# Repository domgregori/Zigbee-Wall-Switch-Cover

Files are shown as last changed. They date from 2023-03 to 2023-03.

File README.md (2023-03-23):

# Zigbee Wall Switch Cover
This is a zigbee button that can go over a standard US wall switch. This can be handy to control smartbulbs (or whatever else) in a place where you are unable to install smart switches, allowing the switch to remain in the on position and activating the bulb with the front buttons.

This is built using [FreePad](https://github.com/diyruz/freepad) firmware for the E18-MS1-PCB zigbee module. For the zigbee coordinator I use [zigbee2mqtt](https://www.zigbee2mqtt.io/)

# Photos

PCB_Front PCB_Back

PCB_On_Wall Case_On_Wall zigbee_switch

# Programming
This is the wiring diagram between the PCB and CC Debugger

WiringDiagram

To program the module, use [TI SmartRF Flash Programmer](https://www.ti.com/tool/FLASH-PROGRAMMER) **NOT v2** and a CC Debugger

Use the DIYRuZ_FreePad_PM3.hex file from [FreePad](https://github.com/diyruz/freepad/releases) releases for longer battery life.
  
# Ordering
You can use the gerber files in the [PCB folder](PCB/) to order from a PCB manufacturer (I used jlcpcb)

### Part list
Parts can be found in [BOM Folder](BOM/bom.csv)
- 2x 2032 Battery Holder
- 3mm LED
- 5-pin 2.54 (standard) header for programming (if using the 3D printed case that I provided, these headers needed to be removed after programming)
- 2x 1k resistors, 0805
- 10k resistor, 0805
- 2x push buttons, 6x6x4.5mm
- E18-MS1-PCB

# Case
The 3D printed case file can be found in the [Case folder](Case/)

Printed with 20% Infill, Front face on bed with supports for the mounting holes

The PCB has 2mm mounting holes, but I did not use them in this case

Case (Custom)

# Notes
- Orient the **"TOP"** part of the PCB towards the direction of the switch (so upside down if your switch in on in the down position)
- Button 1 (SW1) is the pairing button
- Pair using the info at [Freepad: How to join](https://github.com/diyruz/freepad#how-to-join)
- I highly reccomend setting at least one of the buttons to MOMENTARY mode for quicker respose using the [Freedpad: Working modes](https://github.com/diyruz/freepad#work-modes) guide
- Only one battery is required to run but I use 2 so I get a longer run time
- If using zigbee2mqtt, don't use the outdated CC2531 board. It killed my batteries in days and pairing problems. I recomend the Sonoff ZBDongle-P (**Not model ZBDongle-E**)

### How I use mine
- Top button is set to MOMENTARY mode and toggles light on/off
- Bottom button press toggles between scenes from Home Assistant
- Bottom button hold goes into a dimming mode that allows me to brighten with the top button and dim with the bottom button
- Bottom double press sets light to a night light

- I achieve these by using a mix of Home Assistant automations as well as Node Red

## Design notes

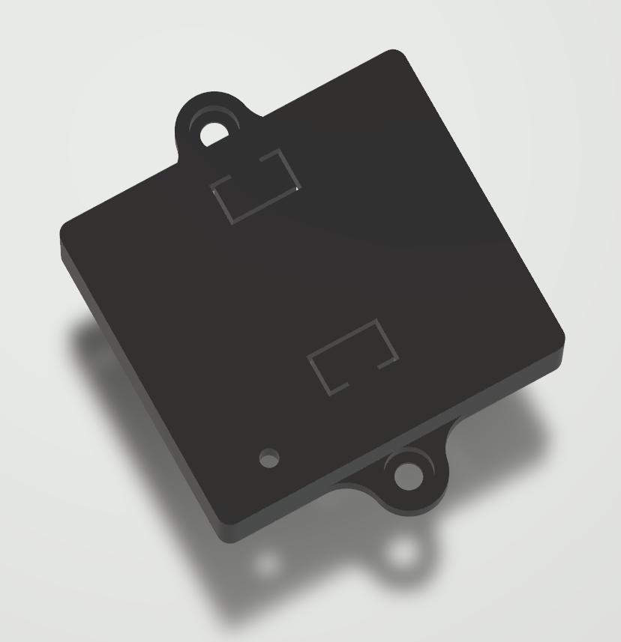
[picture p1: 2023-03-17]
Case/Case.png

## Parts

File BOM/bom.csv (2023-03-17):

Designator | Footprint | Quantity | Value | LCSC Part #
BT1, BT2 | BatteryHolder_Keystone_3002_1x2032 | 2 | Battery_Cell
D1 | LED_D3.0mm | 1 | LED
H1, H2, H3 | MountingHole_2mm | 3 | MountingHole
J1 | PinHeader_1x05_P2.54mm_Vertical | 1 | Debug
R1 | 0805 | 1 | 1k
R2 | 0805 | 1 | 1k
R3 | 0805 | 1 | 10k
SW1, SW2 | SW_PUSH_6mm_H4.3mm | 2 | SW_Push
U1 | E18-MS1-PCB | 1 | E18-MS1-PCB

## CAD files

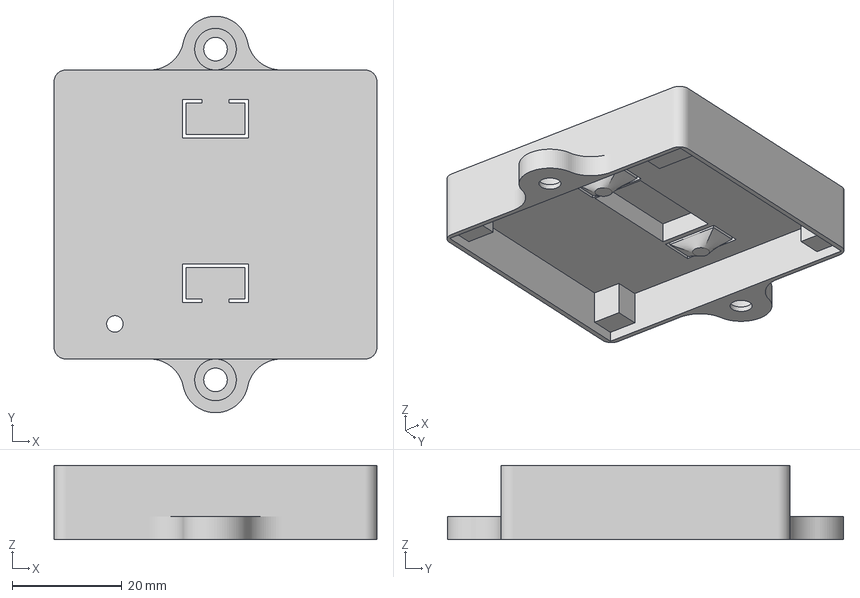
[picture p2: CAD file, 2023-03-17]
Case/ZigbeeWallSwitchCase.3mf
58.9 x 72.3 x 13.6 mm
